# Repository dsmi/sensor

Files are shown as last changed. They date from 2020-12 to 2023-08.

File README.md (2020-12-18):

# Sony Smart Tennis Sensor housing replacement

This is a model of the bottom part of the housing of the Smart Sony Tennis Sensor, made with [OpenSCAD](https://www.openscad.org/).

This tennis sensor, introduced by Sony in 2014 and discontinued in 2016, is a cool and useful device.
It is known to have problems with battery and with the bottom part of the housing, which is also the mounting lug, cracking into pieces.
The battery can be replaced (order CP1254 and solder it), and here it the replacement for the cracking housing!
If printed using SLS (selective laser sintering) from Nylon 12, it is both strong and accurate enough to replace the original housing.
My impression is that it is actually stronger than the original one, and nylon is known to be crack-resistant, so it should hold better than the original one.
I have been able to successfully repair two sensors with this part, and both work well!
Here is how it looks like:

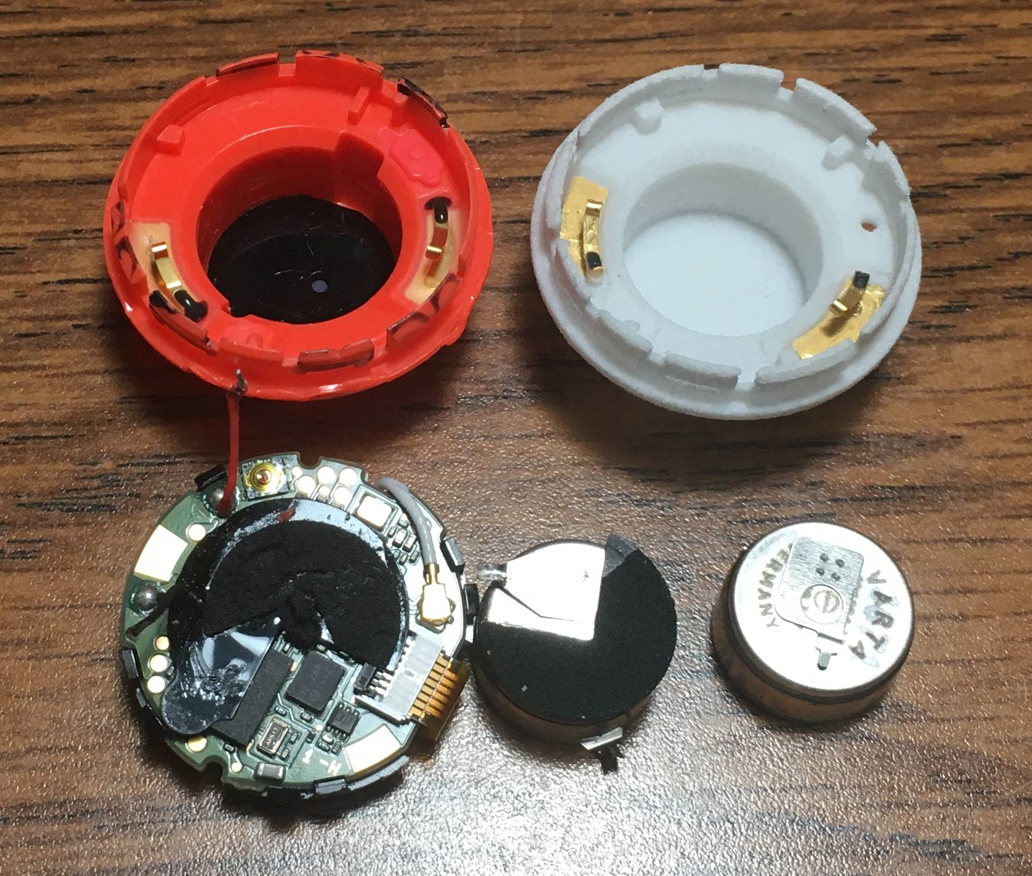
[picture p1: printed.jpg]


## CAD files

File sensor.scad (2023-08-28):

// Segments in a circle, increase for the final render
$fn = 120;

// My Anet A8, which I use to debug this
//  Nozzle diameter: 0.4mm
//  Layer thickness: 0.08, 0.12, 0.16... in increments of 0.04mm

// Units are mm!
hplug = 7.68;   // Height of the bottom 'plug'
r1    = 7.85; // Bottom radius of the plug
r2    = 9.2; // Upper radius of the plug
rcut  = 7.3; // radius of the cuts in the plug
rr = 2.0;  // rounding at the bottom
ru = 0.2;  // rounding at the top
hc = 0.96; // start height for both cuts
h1 = 2.40; // first cut height
h2 = 1.44;  // second cut height
cc = 0.6;  // cut corner
hd = 1.20;  // supporting disk height
rd = 25.6/2; // supporting disk radius
support_d = 11.0; // supporting distance -- const h when varying rounding
support_r = rd*12; // rounding of the supporting disk
sh = 3.60; // skirt height
skirt_r = 11.7; // skirt radius (11.7 is measured, 0.05 oversintering)
skirt_inr = skirt_r - 0.6; // inner radius (0.6 measured, 0.5 oversintering)
skirt_top = 4.56; // = -z of the skirt top
skirt_cham = 0.12*4; // skirt chamfer height (not used now)

// Cutout angles
c1a0 = 0;
c1a1 = -36;
c1a2 = -66;
c2a0 = 171;
c2a1 = 150;
c2a2 = 125;

// Lock crests (initial angles [ -120, 104, 14 ])
lock_a  = [ -120, 105, 14 ]; // angles of the lock 'crests'
lock_r  = 0.6;  // lock crests radius
lock_h  = 0.8;  // heigth of each crest, including radius
lock_r1 = 8.5;  // lock crests start
lock_r2 = rd;   // lock crests end

// Bottom cutouts
cut_o = 5; // offset, where the cutouts start
cut_l = 2; // length of the cutouts
cut_r  = 4;  // radius of the cutout itself
cut_d = 0.36; // depth of the cutouts
cut_a  = [ -64, -153, 118, 27 ]; // angles

// Skirt cuts, angle and depth for each
skirt_cuts = [ [ 13.0, 1.0 ], [ 42.0, 2.2 ], [ 79.0, 2.2 ],
               [ 136, 1.0 ], [ 162.5, 2.2 ],
               [ -13.0, 1.0 ], [ -42.0, 2.2 ], [ -79.0, 2.2 ],
               [ -136, 1.0 ], [ -162.5, 2.2 ] ];
/* skirt_cuts = [ ]; */
skirt_cut_w = 0.8; // width of each cut

// skirt grip height, thickness and angles
skirt_grip_h = 0.8;
skirt_grip_t = 0.6;
skirt_grip_angles = [ [ 42.0-180.0, 79.0-180.0 ],
                      [ -79.0-180.0, -42.0-180.0 ],
                      [ 162.5-180.0, -162.5-180.0 ] ];
/* skirt_grip_angles = [ ]; */

// scirt cutouts for the board assembly grips, [ angle width ]
board_cuts = [ [ -25.5, 3.0 ], [ -125.5, 3.0 ],
               [  25.5, 3.0 ], [  125.5, 3.0 ],];
board_cut_d = 2.5; // 'depth' from the top of the skirt
board_cut_h = 0.6; // height of the cuts



// board assembly directors, angle and h to the skirt top
board_dirs = [ [ 0.0, 0.0 ], [ 205.0-0.5, 0.96 ] ];
dir_width = 0.8; // width of each director
dir_r0 = skirt_inr - 0.8; // starting r of each director

// board assembly supports, angle, width, len
board_sups = [ [ 0.0, 3.0, 1.0 ], [ 112.5, 1.6, 1.6 ],
               [ 190.0, 1.0, 2.0 ], [ -59.5, 1.0, 2.0 ] ];
board_sup_h = 2.1; // height from top of the skirt

// contacts and cradles
cont_r0 = 9.0;
cont_r1 = 10.6;
ccrad_d = 0.36; // contact cradle depth
ccrad_r0 = 8.1; // contact cradle start
ccrad_r1 = 11.0; // contact cradle end

contact_angles = [ [ -72.9, -108.5 ], [ 71.2, 34.6  ] ];
cradle_xangle = 8;
cradle_angles = [ [ -72.9+cradle_xangle, -108.5-+cradle_xangle ],
                  [ 71.2+cradle_xangle, 34.6-cradle_xangle  ] ];

// battery bay
batr = 6.7;  // radius
bath = 7.08; // height

// Sagging of the battery bay
sag_h = 1.0; // height
sag_r = 1.0; // radius increase
sag_r2 = 3.3; // partial sagging radius
sag_a0 = -5.0; // partial sagging start angle
sag_a1 = -55.0; // partial sagging end angle

// reset button hole
reset_a = -138.5; // angle
reset_r = 9.7; // distance from center
reset_hr = 0.7; // hole radius


/**
 * Plug cone
 */
module plug_cone( )
{
  hull()
  {
    rotate_extrude()
    {
      translate([r2-ru, 0]) circle(ru, $fn=8);
      translate([r1-rr, (hplug-rr)]) circle(rr, $fn=24);
    }
  }
}

/**
 * Shape to cut a pie slice, angles a1-a2.
 */
module pie_cut( h, r, a1, a2 )
{
  rotate( [ 0, 0, a1 ] )
  {
    translate( [ -r, 0, 0 ] )
    {
      cube( [ r*2, r*2, h*1.1 ], center = true );
    }
  }
  rotate( [ 0, 0, a2 ] )
  {
    translate( [ r, 0, 0 ] )
    {
      cube( [ r*2, r*2, h*1.1 ], center = true );
    }
  }
}

/**
 * Pie slice of thickness h, radius r, angles a1-a2
 */
module pie( h, r, a1, a2 )
{
  difference( )
    {
      cylinder( h=h, r=r, center = true );
      pie_cut( h, r, a1, a2 );
    }
}

/**
 * Disk on top of the plug
 */
module supporting_disk( )
{
  sr2 = support_r*support_r;
  sd2 = support_d*support_d;
  so = sd2 < 1e5 ? support_r - sqrt( sr2 - sd2 ) : 0.0; // keep support h
  intersection( )
  {
    translate( [ 0, 0, -hd ] ) { cylinder( h=hd+so, r=rd ); }
    if ( support_r < 1e3 )
    {
      translate( [ 0, 0, -(support_r-so) ] ) { sphere( r=support_r, $fn=400 ); }
    }
  }
}

/**
 * Cutout in the plug
 */
module cutout( h, hc, h1, a0, a1, a2 )
{
  difference( )
    {
      union( )
        {
          translate( [ 0, 0, h1/2+hc ] )
          {
            pie( h1, r2, a0, a2 );
          }
          translate( [ 0, 0, h/2+hc ] )
          {
            pie( h, r2, a0, a1 );
          }
          translate( [ 0, 0, h1+hc ] )
          {
            rotate( [ 0, 0, a1 ] )
            {
              translate( [ 0, rcut, 0 ] )
              {
                rotate( [ 0, 45, 0 ] )
                {
                  cube( [ cc*2, cc*5, cc*2 ], center = true );
                }
              }
            }
          }
        }
      translate( [ 0, 0, h/2+hc ] )
        {
          cylinder( h=h*1.1, r=rcut, center = true );
        }
    }
}

// cutouts in the bottom of the plug (remove?)
module bottom_cutouts( )
{
  for ( ang = cut_a )
  {
    rotate( [ 0, 0, ang ] )
    {
      translate( [ 0, cut_o + cut_l/2, hplug + cut_r - cut_d ] )
      {
        rotate( [ 90, 0, 0 ] )
        {
          cylinder( h=cut_l, r=cut_r, center = true );
        }
      }
    }
  }
}

// lock crests on the supporting disk
module lock_crests( )
{
  for ( ang = lock_a )
  {
    rotate( [ 0, 0, ang ] )
    {
      // Rotate crests in accordance with the rounding
      crest_a = asin( support_d / support_r ); // angle
      rotc = [ 0, support_d, 0 ]; // center of rotation
    
      translate ( rotc ) rotate( [ -crest_a, 0, 0 ] ) translate ( -rotc )
      {
        hull( )
        {
          lr = lock_r;
          lh = lock_h - lock_r;
          translate( [ 0, lock_r1 + lr, 0  ] ) { sphere( lr, $fn = 24 ); }
          translate( [ 0, lock_r1 + lr, lh ] ) { sphere( lr, $fn = 24 ); }
          translate( [ 0, lock_r2 - lr, 0  ] ) { sphere( lr, $fn = 24 ); }
          translate( [ 0, lock_r2 - lr, lh ] ) { sphere( lr, $fn = 24 ); }
        }
      }
    }
  }
}

module bottom_plug( )
{
  difference( )
  {
    plug_cone( );

    union( )
    {
      cutout( hplug, hc, h1, c1a0, c1a1, c1a2 );
      cutout( hplug, hc, h2, c2a0, c2a1, c2a2 );
      bottom_cutouts( );
    }
  }
}

// Grips which hold skirt in the upper part
module skirt_grip( )
{
  for ( gangs = skirt_grip_angles )
  {
    difference( )
    {
      cylinder(h = skirt_grip_h,
               r1 = skirt_r,
               r2 = skirt_r+skirt_grip_t );

      pie_cut( skirt_grip_h*2.0, skirt_r*2.0,
               gangs[0], gangs[1] );
    }
  }
}


// Skirt, top at z=0
module skirt( )
{
  difference( )
  {
    union( )
    {
      cylinder( h=sh, r=skirt_r );
      skirt_grip( );
    }
  
    union( )
    {
      // Inner 'hole'
      cylinder( h=sh*4, r=skirt_inr, center=true );
    
      // skirt cuts
      for ( cut = skirt_cuts )
      {
        rotate( [ 0, 0, cut[0] ] )
        {
          translate( [ 0, skirt_r, 0 ] )
          {
            cube( [ skirt_cut_w, skirt_r, cut[1]*2 ], center=true );
          }
        }
      }

      // cuts for the board assembly grips
      for ( cut = board_cuts )
      {
        rotate( [ 0, 0, cut[0] ] )
        {
          translate( [ 0, skirt_r, board_cut_d ] )
          {
            cube( [ cut[1], skirt_r, board_cut_h ], center=true );
          }
        }
      }
    }
  }
}

// board assembly directors
module board_directors( )
{
  for ( bdir = board_dirs )
  {
    dir_l = (skirt_inr+skirt_r)/2.0 - dir_r0; // box length
    dir_h = sh - bdir[1]; // box height
    rotate( [ 0, 0, bdir[0] ] )
    {
      translate( [ 0, dir_r0 + dir_l/2, dir_h/2+bdir[1] ] )
      {
        cube( [ dir_width, dir_l, dir_h ], center=true );
      }
    }
  }
}

// board assembly supports
module board_supports( )
{
  for ( bsup = board_sups )
  {
    sup_r0 = skirt_inr - bsup[2]; // starting r of support
    sup_l = (skirt_inr+skirt_r)/2.0 - sup_r0; // box length
    sup_h = sh - board_sup_h; // box height
    rotate( [ 0, 0, bsup[0] ] )
    {
      translate( [ 0, sup_r0 + sup_l/2, sup_h/2+board_sup_h ] )
      {
        cube( [ bsup[1], sup_l, sup_h ], center=true );
      }
    }
  }
}
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

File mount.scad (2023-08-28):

// Segments in a circle, increase for the final render
$fn = 600;

// My Anet A8, which I use to debug this
//  Nozzle diameter: 0.4mm
//  Layer thickness: 0.08, 0.12, 0.16... in increments of 0.04mm

// Units are mm!
outer_r   = 30/2; // outer disk radius
outer_h   = 1.2;//2.76; // outer disk height
support_r = 25.5/2; // supporting disk radius
support_h = 0.6;  // distance from support to base at support_r
support_s = 25.6/2*12; // rounding of the supporting disk
hplug = 7.44+support_h; // Height of the bottom 'plug'
r1    = 8.2; // Bottom radius of the plug
r2    = 9.2; // Upper radius of the plug
rr = 2.0;  // rounding at the bottom
ru = 0.2;  // rounding at the top

lock_a = [ 180+120, 180-105, 180-14 ]; // angles of the lock 'crests'
lock_ea0 = 36; // lock entrance start angle
lock_ea1 = 8; // lock entrance end angle

// tongues which hold the sensor
tongue_top = -1.2; // top, relative to support_h
tongue_r0 = 7.5;  // inner radius
tongue_r1 = 12.0; // outer radius
tongues = [ [ 45+8, 45-8, 1.2 ], // start-end angles and thickness
            [ 225+16, 225-16, 2.16 ] ]; 

// Trap door dimensions
tdw = 27.5;  // width
tdh = 25.5;  // height
tdd = 27.5;  // distance between the diagonal bevels
tdl = 3.6;   // length (depth)
a   = 45;    // diagonal bevels angle
tow = 23.5;  // width of the opening
toh = 21.5;  // height of the opening

// Trap door cutout to place the grips in
tdcw = 10;
tdch = 8;

// Clips
cth = 1.6;   // thickness of a clip
cl  = 7;     // full length of a clip
c2b = 5.15; // clip-2-base distance
ct2 = 2.4;  // clip thickness at the bottom
cl2 = 1.2;  // length of the thick part above tongue
cto = 2.4;  // length of the tongue of the clip (minus cth)
cw1 = 8;    // width of the first (wider) clip
cw2 = 6;    // width of the second (narrower) clip
cwr = 0.8;  // width of the rests which touch the trap door

// Supports of the clips which touch the sensor
sw = 0.8;
st = 4;  // top of the supports
sb = 7;  // bottom of the supports
ss = 14; // separation between the opposite supports

// support disc cutout (to remove the sensor) width
dcw = 2.8;

/**
 * Shape to cut a pie slice, angles a1-a2.
 */
module pie_cut( h, r, a1, a2 )
{
  rotate( [ 0, 0, a1 ] )
  {
    translate( [ -r, 0, 0 ] )
    {
      cube( [ r*2, r*2, h*1.1 ], center = true );
    }
  }
  rotate( [ 0, 0, a2 ] )
  {
    translate( [ r, 0, 0 ] )
    {
      cube( [ r*2, r*2, h*1.1 ], center = true );
    }
  }
}

/**
 * Pie slice of thickness h, radius r, angles a1-a2
 */
module pie( h, r, a1, a2 )
{
  difference( )
    {
      cylinder( h=h, r=r, center = true );
      pie_cut( h, r, a1, a2 );
    }
}

module plug_cone( )
{
   translate( [ 0, 0, outer_h + support_h ] )
   {
      rotate( [ 180, 0, 0 ] )
      {
         hull()
         {
            rotate_extrude()
            {
               translate([r2-ru, 0]) circle(ru, $fn=8);
               translate([r1-rr, (hplug-rr)]) circle(rr, $fn=24);
            }
         }
      }
   }
}

// Disk that the sensor lies on
module support_disk( )
{
   // support normal angle at support_r from center
   supa = asin( support_r/support_s );

   outz = outer_h + support_s*cos(supa); // z of the outer rounding sphere
   difference( )
   {
      cylinder( h=outer_h, r=outer_r );
      translate( [ 0, 0, outz ] ) sphere( r=support_s/*, $fn=400*/ );
   }

   suph = outer_h+support_h/cos(supa); // support disk edge height above z=0
   supz = suph + support_s*cos(supa); // z of the rounding sphere

   // cut box dimensions
   cbox_side = sqrt( 2*pow(2*support_h,2) );
   cbox_size = [ cbox_side, support_r, cbox_side ]; 

   // entrance cut box dimensions
   ebox_width = support_r * sin( (lock_ea0-lock_ea1)/2.0 );
   ebox_size = [ ebox_width, support_r, ebox_width*2 ];
   
   difference( )
   {
      cylinder( h=suph*2.0, r=support_r );
      translate( [ 0, 0, supz ] ) sphere( r=support_s/*, $fn=400*/ );

      for ( ang = lock_a )
      {
         rotate( [ 0, 0, ang ] )
         {
            translate( [ 0, support_r, outer_h + 1.9*support_h ] )
            {
               rotate( [ supa, 0, 0 ] ) rotate( [ 0, 45, 0 ] )
               {
                  cube( cbox_size, center=true );
               }
            }
         }
      }

      for ( ang = lock_a )
      {
         rotate( [ 0, 0, ang+lock_ea0 ] )
         {
            translate( [ 0, support_r, outer_h + support_h ] )
            {
               rotate( [ supa, 0, 0 ] )
               {
                  translate( [ ebox_width/2, 0, 0 ] )
                  {
                     cube( ebox_size, center=true );
                  }
               }
            }
         }
      }
      
      for ( ang = lock_a )
      {
         rotate( [ 0, 0, ang+lock_ea1 ] )
         {
            translate( [ 0, support_r, outer_h + support_h ] )
            {
               rotate( [ supa, 0, 0 ] ) rotate( [ 0, 60, 0 ] )
               {
                  translate( [ -ebox_width/2, 0, 0 ] )
                  {
                     cube( ebox_size, center=true );
                  }
               }
            }
         }
      }
   }
}

module support_disk_cutout( )
{
   // Length of the cutting box, we just need some large
   // enough value
   l = outer_r;

   // Distance from the center to cutout
   r = tdh/2; // same where the trap door starts

   // Height of the cutting box, some value > disk h
   h = outer_h*3;

   translate( [ 0, r+l/2, 0 ] )
   {
      cube( [ dcw, l, h ], center = true );
   }
}


// Trap door which has the shape of hexagonal prism
module trap_door( w, h, d, l )
{
   intersection( )
   {
      cube( [ w, h, l ], true );
      rotate( [ 0, 0, a ] )
      {
         cube( [ d,   d*2, l ], true );
      }
      rotate( [ 0, 0, -a ] )
      {
         cube( [ d,   d*2, l ], true );
      }
   }
}

// Makes x-parallel clip, zero y is where it touches
// the edge of the trap door opening.
module clip( w )
{
   translate( [ 0, -ct2, 0 ] )
   {
      translate( [ -w/2, cth, -cl ] )
      {
         l = cto;      // tongue length
         t = cl - c2b; // tongue thickness
         ra = atan( t/l );
         difference( )
         {
            cube( [ w, l, t ] );
            rotate( [ ra, 0, 0 ] )
            {
               translate( [ 0, 0, -t ] ) cube( [ w, 2*l, t ] );
            }
         }
      }

      translate( [ -w/2, 0, -c2b ] )
      {
         difference( )
         {
            cube( [ w, ct2, cl2 ] );
            translate( [ cwr, 0, 0 ] )
            {
               cube( [ w - 2*cwr, ct2, cl2 ] );
            }
         }
      }

      translate( [ -w/2, 0, -cl ] )
      {
         cube( [ w, cth, cl ] );
      }
   }
}

// Supporting structure which is inside the grip.
module support_inner( )
{
   translate( [ 0, 0, -tdl/2 ] )
   {
      difference( )
      {
         trap_door( tdw, tdh, tdd, tdl );
         
         union( )
         {
            cube( [ tdcw, tdh,  tdl ], center = true );
            cube( [ tdw,  tdch, tdl ], center = true );
         }
      }
   }

   translate( [ 0, toh/2, 0 ] )
   {
      clip( cw1 );
   }

   translate( [ 0, -toh/2, 0 ] )
   {
      rotate( [ 0, 0, 180 ] )
      {
         clip( cw1 );
      }
   }

   translate( [ -tow/2, 0, 0 ] )
   {
      rotate( [ 0, 0, 90 ] )
      {
         clip( cw2 );
      }
   }

   translate( [ tow/2, 0, 0 ] )
   {
      rotate( [ 0, 0, -90 ] )
      {
         clip( cw2 );
      }
   }

   // Height of the clip supports
   sh = sb - st; 

   translate( [ 0, 0, -sb/2 - st/2 ] )
   {
      difference( )
      {
         cube( [ tow - ct2*2, sw, sh ], center = true );
         cube( [ ss,          sw, sh ], center = true );
      }

      difference( )
      {
         cube( [ sw, toh - ct2*2, sh ], center = true );
         cube( [ sw, ss,          sh ], center = true );
      }
   }
}

difference( )
{
   union( )
   {
      difference( )
      {
         support_disk( );
         support_disk_cutout( );
      }
      support_inner( );
   }
   plug_cone( );
}

difference( )
{
   for ( tongue = tongues )
   {
      lz = tongue_top + outer_h + support_h - tongue[2]/2;
      translate( [ 0, 0, lz ] )
      {
         pie( tongue[2], tongue_r1, tongue[0], tongue[1] );
      } 
   }
   cylinder( r=tongue_r0, h=outer_h*10, center=true );
}

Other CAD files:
mount_fdm.scad

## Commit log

2020-11-28 Initial version
    [sensor.scad]
2020-12-05 Add reset button hole and cuts for board assembly grips
    [sensor.scad]
2020-12-06 Changes based on the first test print: (1) plug cuts increased (2) support disk thickness decreased (3) skirt cuts width decreased (4) skirt grips increased (5) contact cradles increased (6) bottom c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
    [sensor.scad]
2020-12-07 More corrections based on the test print: increase plug cutouts, decrease plug height
    [sensor.scad]
2020-12-13 Add picture of the printed part
2020-12-18 Minor changes based on the first working prototype
    [sensor.scad]
2021-01-20 Adjustments in the sensor -- skirt radius changed, lock crests increased
    [sensor.scad]
2021-01-24 Cut corner decreased a bit
    [sensor.scad]
2021-01-24 Draft of the mount
    [mount.scad]
2021-01-25 Make the contact cradles a bit smaller
    [sensor.scad]
2021-11-11 Change height of one of the board directors so it does not block the cover
    [sensor.scad]
2023-08-28 Sensor locks adjustments
    [sensor.scad]
2023-08-28 Initial version of the mount is done!
    [mount.scad]
2023-09-04 FDM-optimized mount added
    [mount_fdm.scad]
2023-10-09 FDM-optimized mount adjustments -- now it works fine and I am currently using it!
    [mount_fdm.scad]
2024-03-17 Mount adjusted, also modified so top and bottom can be printed separately
    [mount_fdm.scad]
2024-03-17 Adjust trap door clips, make them printable w/o support, decrease a bit the plug hole radius
    [mount_fdm.scad]
2024-04-13 Make mount lower, adjust tongues which hold the sensor
    [mount_fdm.scad]
